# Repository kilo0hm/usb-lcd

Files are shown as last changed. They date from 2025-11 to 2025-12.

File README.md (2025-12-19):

# usb-lcd
Connect a HD44780 LCD to USB, via the CH341 IC. This adapter can interface with LCD Smartie, LCDHype, and AIDA64 on Windows. Linux support should be possible too.

See my prototype version working [here](https://www.youtube.com/shorts/TWgQVQCoLs0), and the Rev.A PCB working [here](https://www.youtube.com/watch?v=QafS92o0JMY).

The PCB layout is inspired by the I2C adapter boards commonly found online. It should fit on the back any 16 pin LCD module with a HD44780 (or compatible) driver.

This project was made using the documentation and plugins from ABACOM. You can buy their USB LCD, as well as see all the documentation [here](https://www.electronic-software-shop.com/hardware/usb-lcd-display-4x20-zeichen-gruen.html).

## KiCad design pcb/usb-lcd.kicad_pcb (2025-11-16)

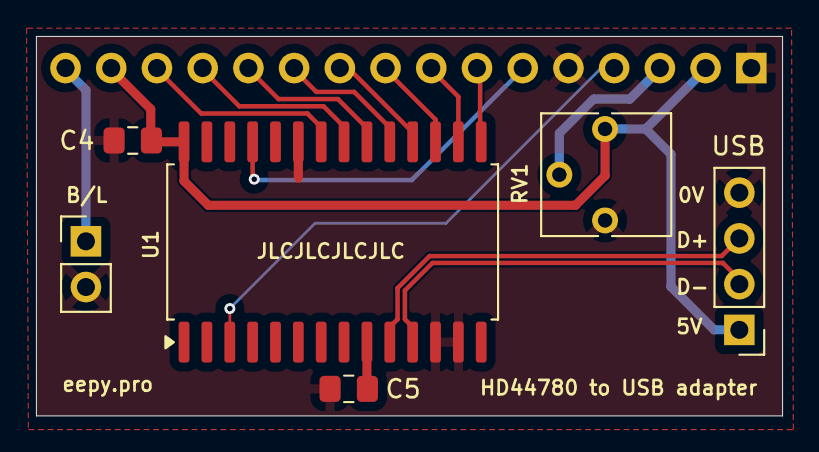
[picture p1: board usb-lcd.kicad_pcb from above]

Board: 2 copper layers, 41.5 x 21.1 mm, 7 parts (1 on the bottom side), 17 nets.

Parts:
C4: 0.1u; C_0805_2012Metric_Pad1.18x1.45mm_HandSolder
C5: 0.01u; C_0805_2012Metric_Pad1.18x1.45mm_HandSolder
J1: USB; PinHeader_1x04_P2.54mm_Vertical
J2: B/L; PinHeader_1x02_P2.54mm_Vertical
J3: LCD; PinHeader_1x16_P2.54mm_Vertical
RV1: 10K; Potentiometer_Vishay_T73YP_Vertical
U1: CH341B-EPP/MEM; SOP-28_8.4x18.16mm_P1.27mm

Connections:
+5V: C4.1, J1.1, J3.2 (VDD), J3.15 (LED(+)), RV1.1, U1.28 (VCC)
/D+: J1.3, U1.10 (UD+)
/D-: J1.2, U1.11 (UD-)
GND: C4.2, C5.2, J1.4, J2.2, J3.1 (VSS), J3.5 (R/W), RV1.3, U1.12 (GND), U1.13 (X1), U1.23 (SDA)
unnamed: J2.1, J3.16 (LED(-))
unnamed: J3.7 (D0), U1.15 (D0)
unnamed: J3.8 (D1), U1.16 (D1)
unnamed: J3.9 (D2), U1.17 (D2)
unnamed: J3.10 (D3), U1.18 (D3)
unnamed: J3.11 (D4), U1.19 (D4)
unnamed: J3.12 (D5), U1.20 (D5)
unnamed: J3.13 (D6), U1.21 (D6)
unnamed: J3.14 (D7), U1.22 (D7)
unnamed: J3.6 (E), U1.25 (WR#)
unnamed: J3.4 (RS), U1.3 (AS#)
unnamed: J3.3 (VO), RV1.2
unnamed: C5.1, U1.9 (V3)

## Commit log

2025-11-11 Add PCB
    [usb-lcd.kicad_pcb, usb-lcd.kicad_sch]
2025-11-16 Update PCB
    [usb-lcd.kicad_pcb, usb-lcd.kicad_sch]
